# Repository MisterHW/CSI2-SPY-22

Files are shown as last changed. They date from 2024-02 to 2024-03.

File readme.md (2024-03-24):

# CSI2-SPY-22



> [!WARNING]  
> Rev.A layout and footprints have not been proven through prototyping yet. Replicate this design based on your own assessment. Follow the updates of this repository to be notified when more results have been added.

## CSI2-SPY-22-1A 

This board fundamentally has two variants integrated into a single PCB. It can be fully populated, or one one side can be left unpopulated. Only one side may be used at a time, since the six broken-out signals are shared, but this allows easy testing under similar conditions with and without the re-timer IC.

- Front side: passive FPC extender with I2C tapping
- Back side. active FPC extender based on the DPHY440 re-timer IC, with I2C tapping

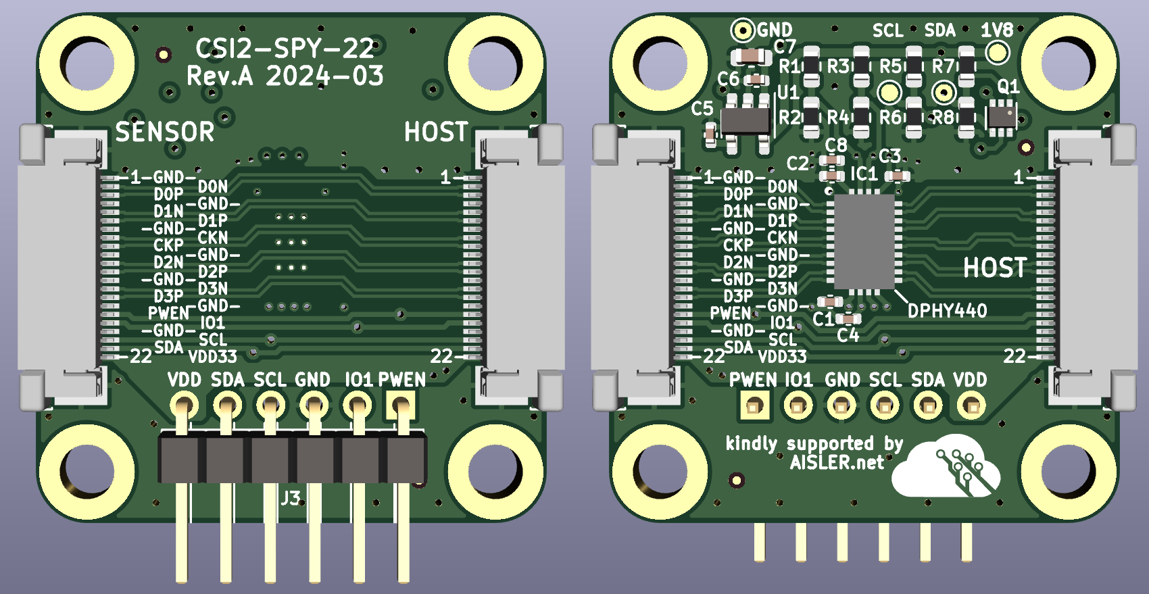
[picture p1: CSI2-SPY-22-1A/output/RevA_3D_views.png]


## Raspberry Pi Camera Debugging

Prior work on https://github.com/jergling/MIPI-Spy offers a 15-pin, 1mm pitch PFC bridge PCB with probe points for all signals. RPI CM4 IO BOARD features one, Raspberry Pi 5 boards feature two 4-lane CSI2 camera ports using 22-pin, 0.5mm pitch FFC headers. 

To obtain access to the associated I2C lines and to be able to hook up a logic analyzer, a matching PCB design is provided in this repository.

## 22-Pin FPC Extender With I2C Connections

CSI2-SPY-22 is a 4-layer board that can be populated in multiple variants:
- front-ony: passive PCB with three headers J1, J2, J3.
- back-only: J3, J4, J5 plus [SN65DPHY440SS](https://www.ti.com/product/SN65DPHY440SS) MIPI® CSI-2/DSI DPHY retimer, LDO and passives. 

Re-timers can be used to zero out skew between lanes and re-transmit data with optional pre-emphasis. Please refer to  [DPHY440 datasheet](https://www.ti.com/lit/ds/symlink/sn65dphy440ss.pdf)  *8.2.2
Detailed Design Procedure* for an appropriate adaption via R1 thru R8.

	The output pins automatically compensate for uneven skew between clock and data lanes received on its 
	inputs ports. The DPHY440 output voltage swing and edge rate can be adjusted by changing the state of
	the VSADJ_CFG0 pin and ERC pin respectively.

Populate Q1 (DMG1024), R5 (2k) and R7 (2k) to enable I2C. 

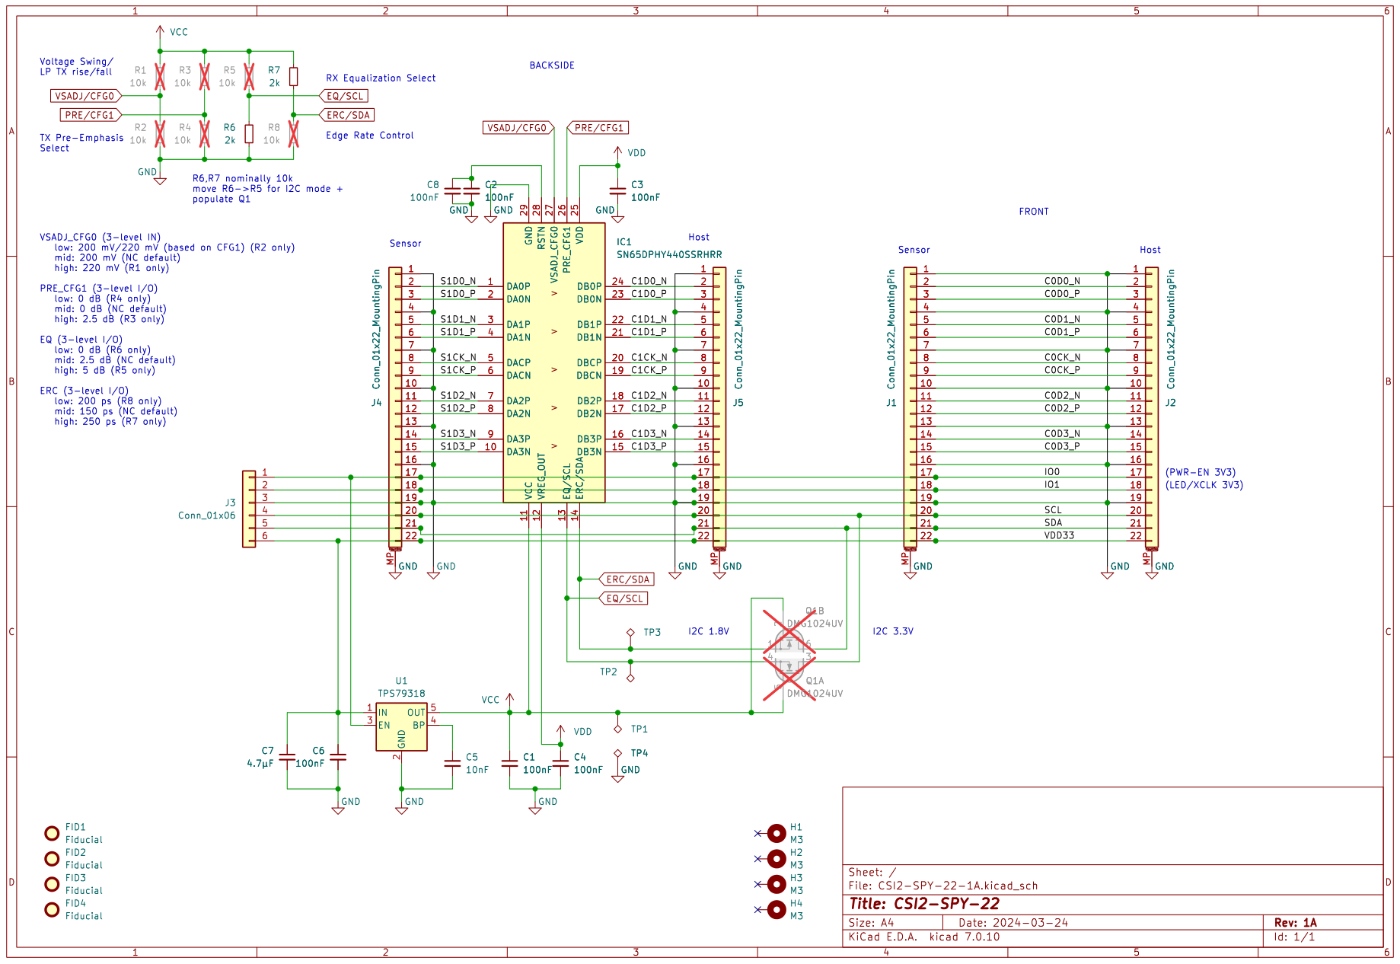
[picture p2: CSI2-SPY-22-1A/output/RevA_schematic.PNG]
RevA_schematic

[Rev-1A schematic (pdf version)](CSI2-SPY-22-1A/output/RevA_schematic.pdf)

## Raspberry Pi 5 Connectors

On The Raspberry Pi 5 board, the connector name labels J3 and J4 are not used as Pin 1 location indicators. 
- Note RPi 5 J3 and J4 Pin 1 locations are on the inward facing side of the ZIF FPC connectors.
- Orient CSI2-SPY-22 based on the Pin 1 and Pin 22 markings on the board.
- Use a **same-side 22-pin 0.5mm** pitch flex print cable to connect the CSI2-SPY-22 board HOST side to RPi 5 CAM/DISP headers.
- Erroenous connection (with an opposite-side flex print cable) will either lead to a disconnected state or the RPi 5 3.3V power rail will be shorted to GND.

Raspberry Pi 5 camera connectors:

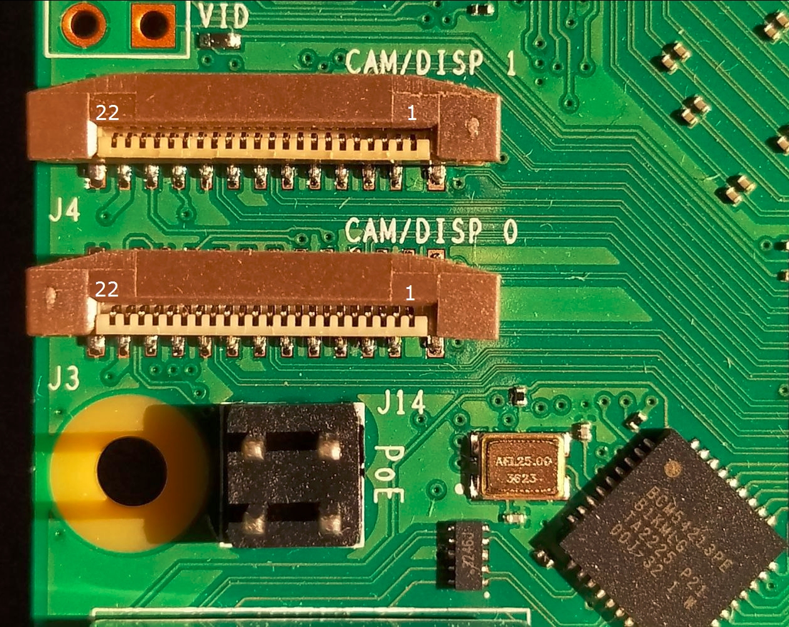
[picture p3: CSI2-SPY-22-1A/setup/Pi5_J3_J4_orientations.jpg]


## iBOM

via htmlpreview.github.io: [2024-03-24_bom/ibom.html](http://htmlpreview.github.io/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) 

## License

KiCad project: copyright Helge Wurst 2024.

This source describes Open Hardware and is licensed under the CERN-OHL-S v2.

You may redistribute and modify this source and make products using it under the terms of the CERN-OHL-S v2 (https://ohwr.org/cern_ohl_s_v2.txt).

This source is distributed WITHOUT ANY EXPRESS OR IMPLIED WARRANTY, INCLUDING OF MERCHANTABILITY, SATISFACTORY QUALITY AND FITNESS FOR A PARTICULAR PURPOSE. Please see the CERN-OHL-S v2 for applicable conditions.

Source location: https://github.com/MisterHW/CSI2-SPY-22

As per CERN-OHL-S v2 section 4, should You produce hardware based on this source, You must where practicable maintain the Source Location visible on the external case of the Gizmo or other products you make using this source.

## Changes

- 2024-03 Rev. 1A release with part numbers and consolidated BOM
- 2024-02 Rev. 1A pre-release and initial documentation.

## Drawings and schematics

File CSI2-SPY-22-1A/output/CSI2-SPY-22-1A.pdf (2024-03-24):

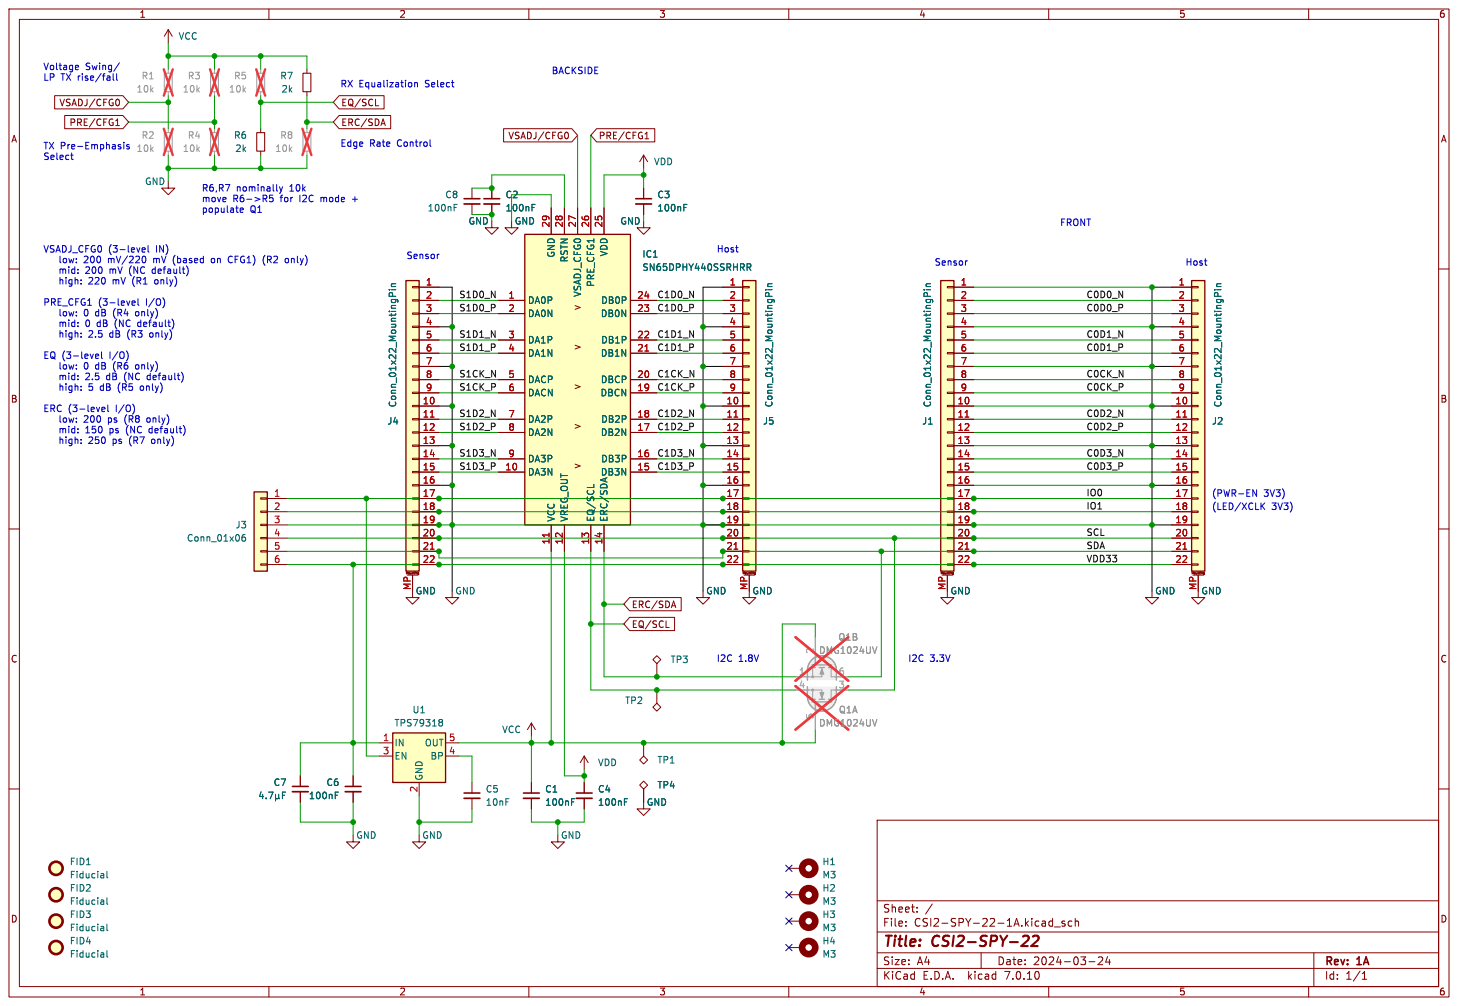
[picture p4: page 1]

low: 0 dB (R4 only) mid: 0 dB (NC default)

low: 0 dB (R6 only) mid: 2.5 dB (NC default)

low: 200 ps (R8 only) mid: 150 ps (NC default)

5 Q1B DMG1024UV GND GND GND GND

2 EN 3 BP 4 OUT 5 U1 TPS79318 GND GND

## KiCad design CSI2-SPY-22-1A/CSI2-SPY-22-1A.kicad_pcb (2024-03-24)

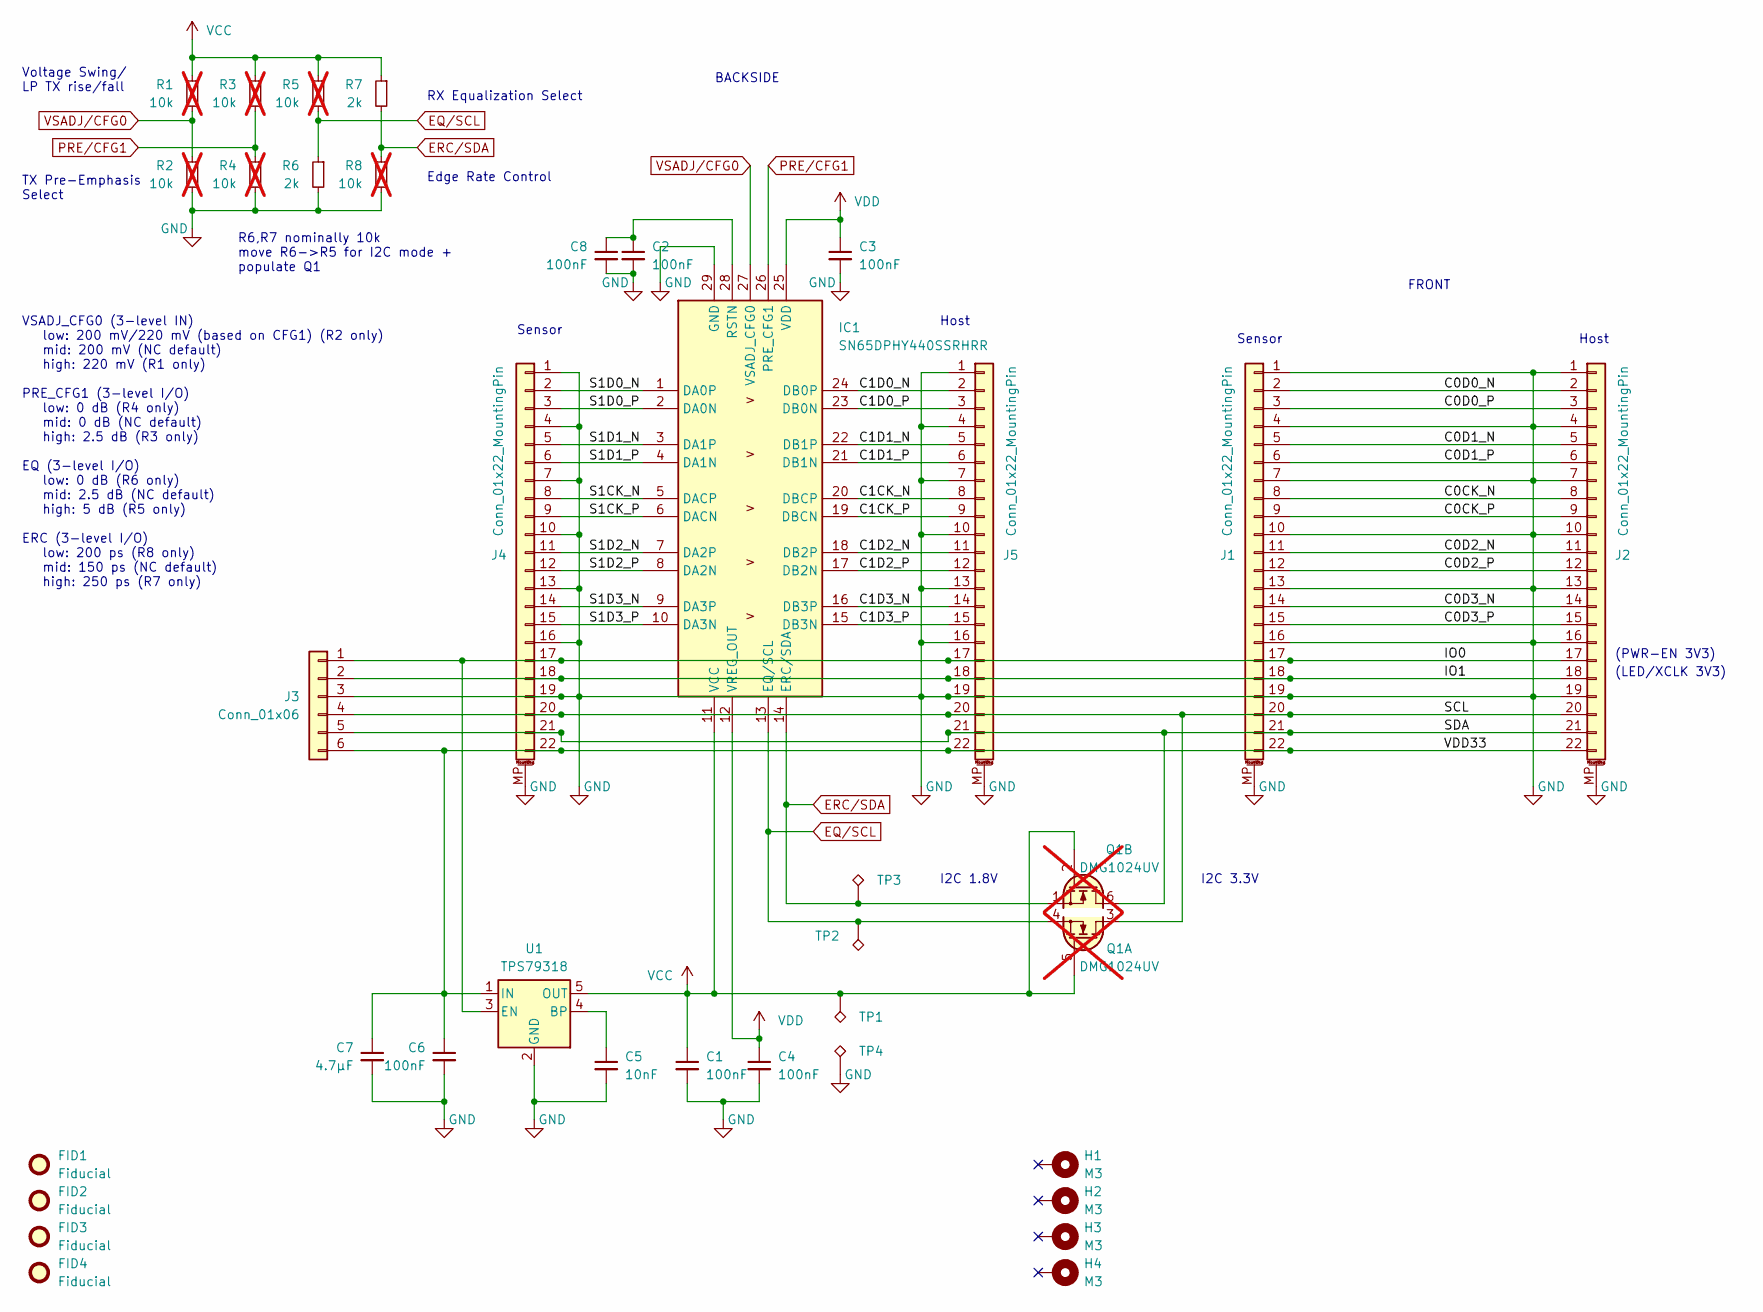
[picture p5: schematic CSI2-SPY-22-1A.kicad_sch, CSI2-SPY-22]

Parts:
C1, C2, C3, C4, C6, C8: 100nF; C_0402_1005Metric; Mouser Part Number 80-C0402C104K4R
C5: 10nF; C_0402_1005Metric; Mouser Part Number 81-GRM1555CYA103GE1D
C7: 4.7µF; C_0603_1608Metric; Mouser Part Number 581-0603YW475KAT2A
FID1, FID2, FID3, FID4: Fiducial; Fiducial_0.5mm_Mask1mm
H1, H2, H3, H4: M3; MountingHole_3.2mm_M3_DIN965_Pad
IC1: SN65DPHY440SSRHRR; WQFN28EP-RHR0028A; Manufacturer_Part_Number SN65DPHY440SSRHRR; Mouser Part Number 595-N65DPHY440SSRHRR
J1, J4: Conn_01x22_MountingPin; TE_2-1734839-2_1x22-1MP_P0.5mm_Horizontal; Mouser Part Number 649-F32Q-1A7H1-11022
J2, J5: Conn_01x22_MountingPin; TE_2-1734839-2_1x22-1MP_P0.5mm_Horizontal_TopContact_Reverse; Mouser Part Number 649-F32Q-1A7H1-11022
J3: Conn_01x06; PinHeader_1x06_P2.54mm_Horizontal; Mouser Part Number 649-1012937990602BLF
Q1: DMG1024UV; SOT-563; Mouser Part Number 621-DMG1024UV-7; not fitted
R1, R2, R3, R4, R5, R8: 10k; R_0603_1608Metric; Mouser Part Number 603-RC0603FR-07510KL; not fitted
R6, R7: 2k; R_0603_1608Metric; Mouser Part Number 71-CRCW0603-2.0K-E3
TP1, TP2, TP3, TP4: TestPoint_Alt; TestPoint_Pad_D1.0mm
U1: TPS79318; SOT-23-5; Mouser Part Number 595-TPS79318DBVREP

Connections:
/C0CK_N: J1.8, J2.8
/C0CK_P: J1.9, J2.9
/C0D0_N: J1.2, J2.2
/C0D0_P: J1.3, J2.3
/C0D1_N: J1.5, J2.5
/C0D1_P: J1.6, J2.6
/C0D2_N: J1.11, J2.11
/C0D2_P: J1.12, J2.12
/C0D3_N: J1.14, J2.14
/C0D3_P: J1.15, J2.15
/C1CK_N: IC1.20 (DBCP), J5.8
/C1CK_P: IC1.19 (DBCN), J5.9
/C1D0_N: IC1.24 (DB0P), J5.2
/C1D0_P: IC1.23 (DB0N), J5.3
/C1D1_N: IC1.22 (DB1P), J5.5
/C1D1_P: IC1.21 (DB1N), J5.6
/C1D2_N: IC1.18 (DB2P), J5.11
/C1D2_P: IC1.17 (DB2N), J5.12
/C1D3_N: IC1.16 (DB3P), J5.14
/C1D3_P: IC1.15 (DB3N), J5.15
/IO0: J1.17, J2.17, J3.1, J4.17, J5.17, U1.3 (EN)
/IO1: J1.18, J2.18, J3.2, J4.18, J5.18
/S1CK_N: IC1.5 (DACP), J4.8
/S1CK_P: IC1.6 (DACN), J4.9
/S1D0_N: IC1.1 (DA0P), J4.2
/S1D0_P: IC1.2 (DA0N), J4.3
/S1D1_N: IC1.3 (DA1P), J4.5
/S1D1_P: IC1.4 (DA1N), J4.6
/S1D2_N: IC1.7 (DA2P), J4.11
/S1D2_P: IC1.8 (DA2N), J4.12
/S1D3_N: IC1.9 (DA3P), J4.14
/S1D3_P: IC1.10 (DA3N), J4.15
/SCL: J1.20, J2.20, J3.4, J4.20, J5.20, Q1.3 (D2)
/SDA: J1.21, J2.21, J3.5, J4.21, J5.21, Q1.6 (D1)
/VDD33: C6.1, C7.1, J1.22, J2.22, J3.6, J4.22, J5.22, U1.1 (IN)
EQ/SCL: IC1.13 (EQ/SCL), Q1.4 (S2), R5.2, R6.1, TP2.1
ERC/SDA: IC1.14 (ERC/SDA), Q1.1 (S1), R7.2, R8.1, TP3.1
GND: C1.2, C2.2, C3.2, C4.2, C5.2, C6.2, C7.2, C8.2, IC1.29 (GND), J1.1, J1.4, J1.7, J1.10, J1.13, J1.16, J1.19, J1.MP (MountPin), J2.1, J2.4, J2.7, J2.10, J2.13, J2.16, J2.19, J2.MP (MountPin), J3.3, J4.1, J4.4, J4.7, J4.10, J4.13, J4.16, J4.19, J4.MP (MountPin), J5.1, J5.4, J5.7, J5.10, J5.13, J5.16, J5.19, J5.MP (MountPin), R2.2, R4.2, R6.2, R8.2, TP4.1, U1.2 (GND)
unnamed: C2.1, C8.1, IC1.28 (RSTN)
unnamed: C5.1, U1.4 (BP)
PRE/CFG1: IC1.26 (PRE_CFG1), R3.2, R4.1
VCC: C1.1, IC1.11 (VCC), Q1.2 (G1), Q1.5 (G2), R1.1, R3.1, R5.1, R7.1, TP1.1, U1.5 (OUT)
VDD: C3.1, C4.1, IC1.12 (VREG_OUT), IC1.25 (VDD)
VSADJ/CFG0: IC1.27 (VSADJ_CFG0), R1.2, R2.1

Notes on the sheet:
Sensor
Host
BACKSIDE
(PWR-EN 3V3)
(LED/XCLK 3V3)
I2C 1.8V
RX Equalization Select
Voltage Swing/ LP TX rise/fall
I2C 3.3V
TX Pre-Emphasis Select
FRONT
VSADJ_CFG0 (3-level IN) low: 200 mV/220 mV (based on CFG1) (R2 only) mid: 200 mV (NC default) high: 220 mV (R1 only) PRE_CFG1 (3-level I/O) low: 0 dB (R4 only) mid: 0 dB (NC default) high: 2.5 dB (R3 only) EQ (3-level I/O) low: 0 dB (R6 only) mid: 2.5 dB (NC default) high: 5 dB (R5 only) ERC (3-lev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
Edge Rate Control
R6,R7 nominally 10k move R6->R5 for I2C mode + populate Q1

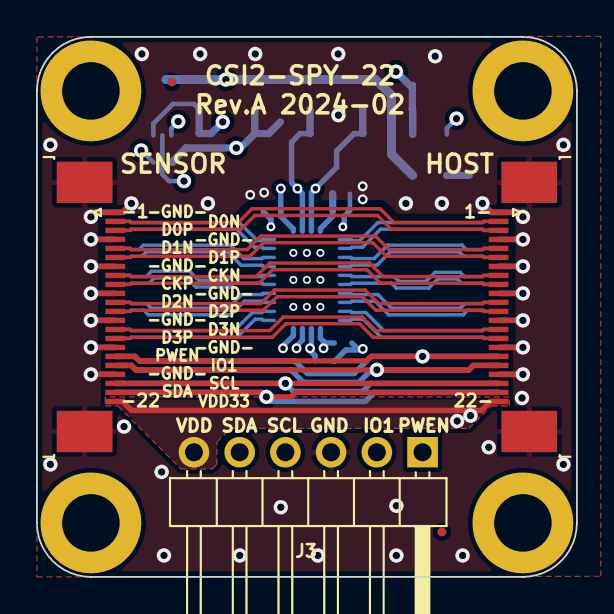
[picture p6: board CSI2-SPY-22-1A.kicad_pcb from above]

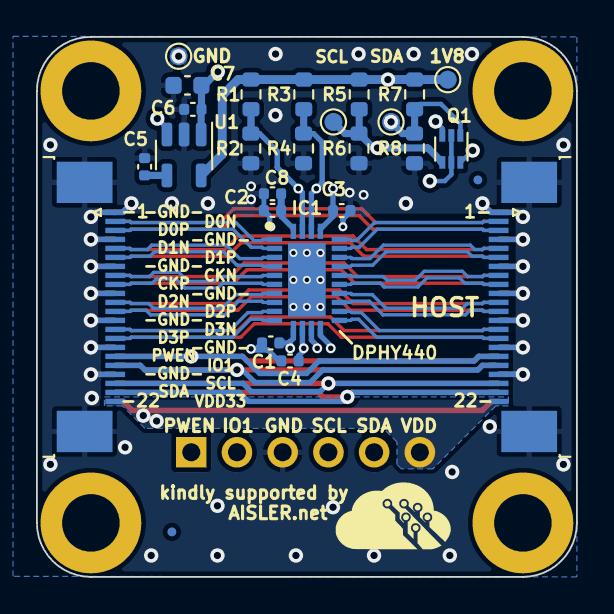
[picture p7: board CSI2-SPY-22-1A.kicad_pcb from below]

Board: 4 copper layers, 30.0 x 30.0 mm, 36 parts (27 on the bottom side), 44 nets.

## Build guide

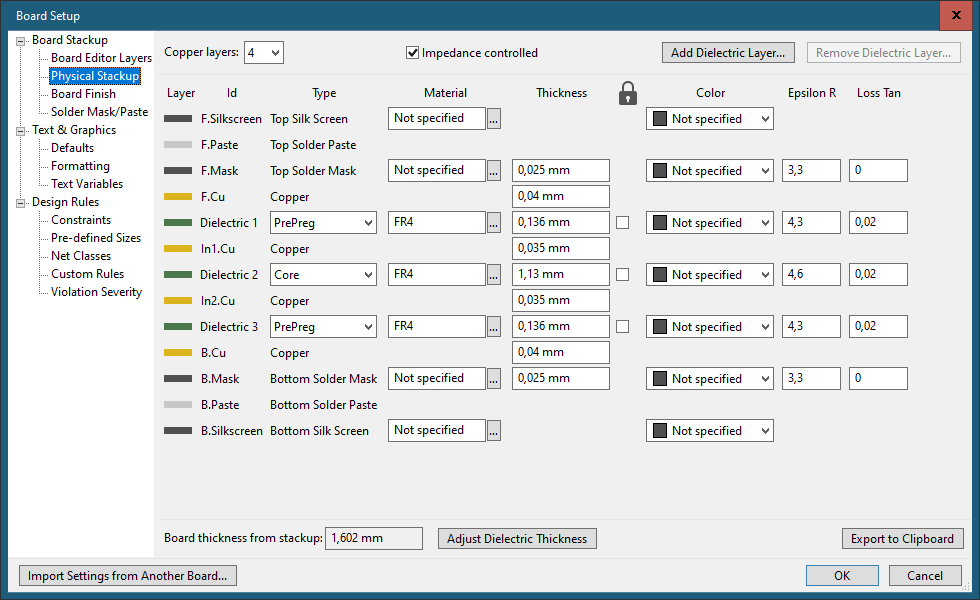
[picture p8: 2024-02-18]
CSI2-SPY-22-1A/setup/physical stackup.png

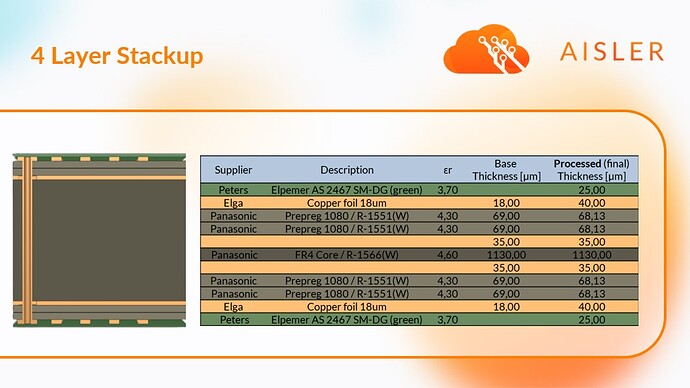
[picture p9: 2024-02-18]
CSI2-SPY-22-1A/setup/4L_structure.jpeg

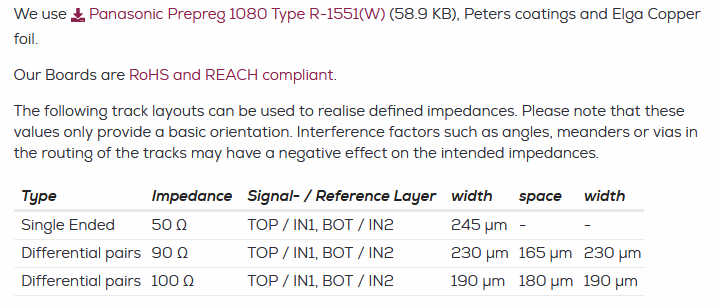
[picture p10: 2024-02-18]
CSI2-SPY-22-1A/setup/dp_width_gap.png

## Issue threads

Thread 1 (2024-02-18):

Add LEDs

MisterHW, 2024-02-18:
As a basic UX improvement, some LEDs may be added to indicate
- presence of 3.3V power, confirming the appropriate orientation of the flex cable between the CSI2-SPY-22 HOST side and SBC camera connector
- I2C activity
- states of PWR-EN and IO1

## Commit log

2024-02-18 initial commit
    Rev.A project files as ordered from AISLER.net
    [CSI2SPY22-B_Cu.gbr, CSI2SPY22-B_Mask.gbr, CSI2SPY22-B_Paste.gbr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]
2024-03-24 restructure project
    [CSI2SPY22-1A.kicad_pcb, CSI2SPY22-1A.kicad_sch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]
2024-03-24 Rev-1A 2024-03 update
    [CSI2-SPY-22-1A-B_Cu.gbr, CSI2-SPY-22-1A-B_Mask.gbr, CSI2-SPY-22-1A-B_Paste.gbr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]
2024-03-24 remove outdated duplicates
    [CSI2SPY22-1A.kicad_pcb, CSI2SPY22-1A.kicad_sch]
